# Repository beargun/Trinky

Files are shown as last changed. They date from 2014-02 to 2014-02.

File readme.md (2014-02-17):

Trinky
=========

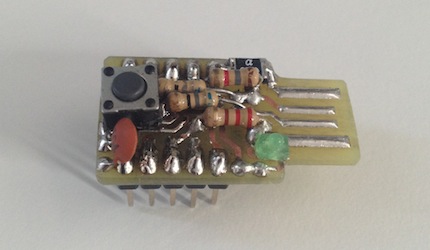
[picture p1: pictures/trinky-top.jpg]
Trinky


## A Trinket clone using only through-hole components

The goal of this project was to create a [Trinket](https://github.com/adafruit/Adafruit-Trinket-USB) clone using only through-hole components. 

### Goals

*   **Use only though-hole components**. Since there are no through-hole mini-USB B sockets, I opted for a USB A etched right on the board (similar to the [Digispark](http://digistump.com/products/1))
*   **Small footprint**. Get it at least as small as the original Trinket.
*   **Optional fuse**. I'm really fond of my USB ports, so for extra peace of mind I added a poly-fuse. I choose a surface-mount ptc fuse, as they tend to be faster than through hole versions. This fuse is optional (as it would break the first goal).  
*   **Different bootloader**. I slightly [altered the bootloader](https://github.com/beargun/Adafruit-Trinket-Gemma-Bootloader), to have it go into programming mode, only when the reset button is pressed. So when you power it up, your code will run immediately, instead of after 10 seconds.
*   **No voltage regulator**. The ATtiny85 will work on 2.7-5.5V. If you power your project using batteries, a voltage regulator will just decrease battery file. Just choose a battery with less than 5.5V. Also, I didn't have room for it. 

### Creating the board

Transfering the layout to the board using toner-transfer. You can see some paper residue on the toner. This doesn't hinder the etching
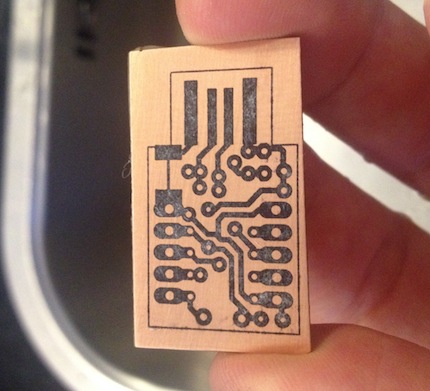
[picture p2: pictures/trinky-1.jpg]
Trinky
<br />

Etching the board in hydrochloric acid and hydrogen peroxide. I'm agitating the board using a modified cd-rom drive.
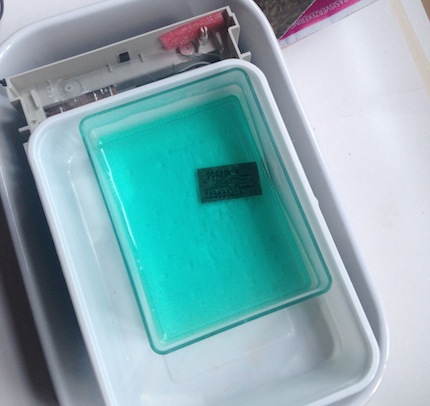
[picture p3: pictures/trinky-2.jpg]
Trinky
<br />

Almost done.
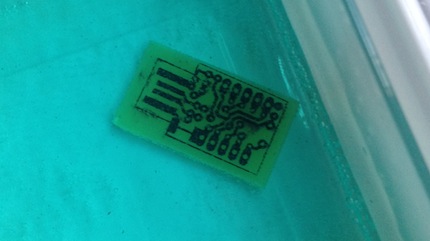
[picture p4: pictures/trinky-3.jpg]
Trinky
<br />

If you look closely you still see some copper. In hindsight I should have left it in the etching solution a bit longer.
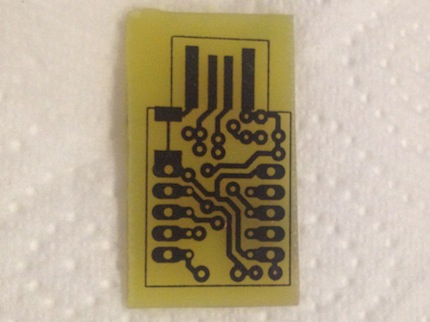
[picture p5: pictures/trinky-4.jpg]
Trinky
<br />

With the toner removed you can clearly see the copper bridge. Easily fixed with a sharp knife.
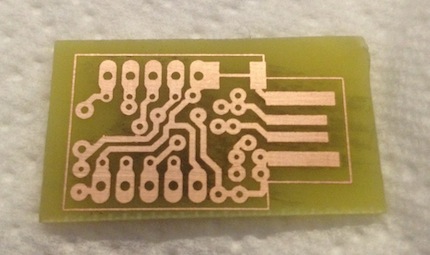
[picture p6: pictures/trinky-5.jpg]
Trinky
<br />

All fixed. Note that I also cut away some of the outline. Otherwise I couldn't test for short using my multimeter
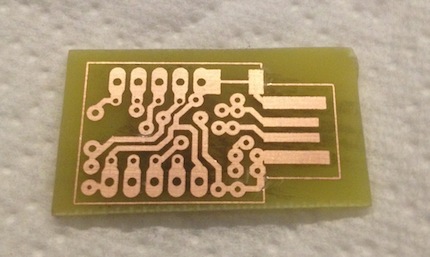
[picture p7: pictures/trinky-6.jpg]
Trinky
<br />

Holding it against the light reveals there are no more obvious shorts.
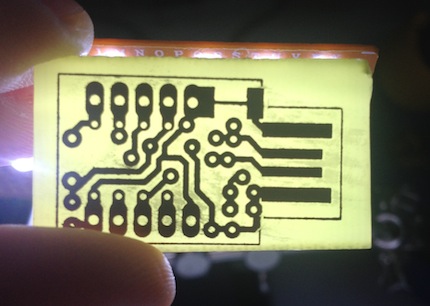
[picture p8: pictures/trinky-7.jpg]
Trinky
<br />

Holes drilled.
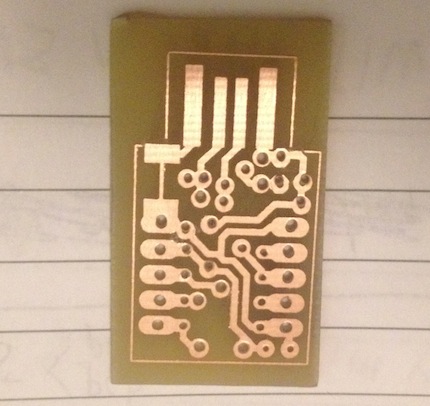
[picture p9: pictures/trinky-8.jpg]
Trinky
<br />

Outline cut using an electric scroll saw.
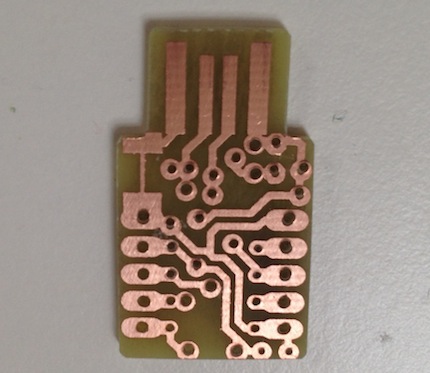
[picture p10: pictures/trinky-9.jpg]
Trinky
<br />

### Assembling the board

Since the led has to be at the top (the same side as the copper), I put the leads down, and then back up in the holes next to it. Otherwise you can't have the led flush with the board, as you have to be able to put the soldering iron underneath it.
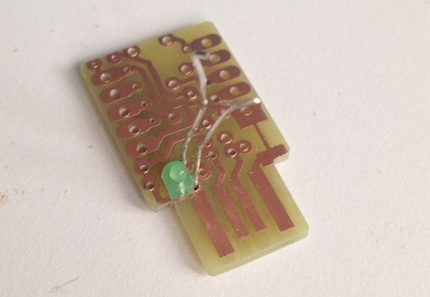
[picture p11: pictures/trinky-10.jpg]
Trinky
<br />
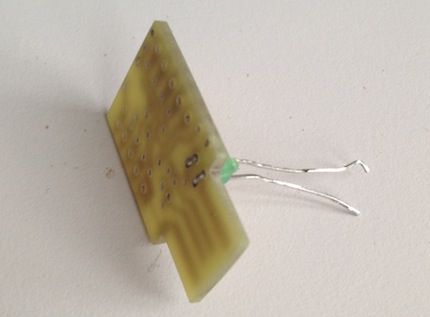
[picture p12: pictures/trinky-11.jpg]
Trinky
<br />

Next add a jumper and the two zener diodes to the underside, and solder it.
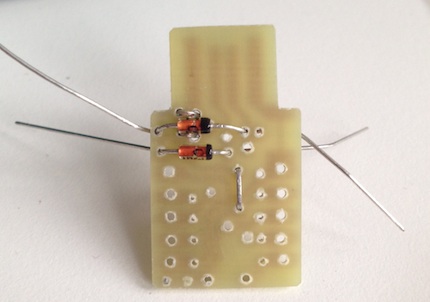
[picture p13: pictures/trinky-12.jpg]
Trinky
<br />
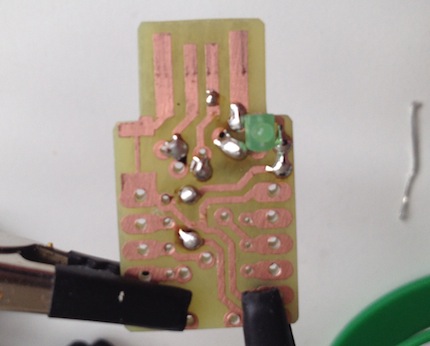
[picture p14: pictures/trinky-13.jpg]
Trinky
<br />

The resistor for the led.
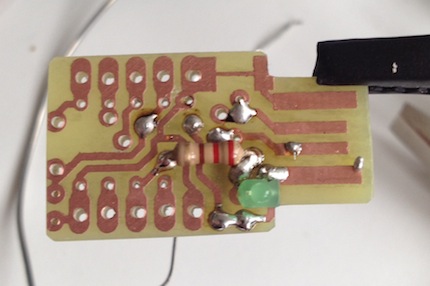
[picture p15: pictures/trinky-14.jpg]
Trinky
<br />

The two 68-Ohm resistors. **You should move the resistors more to the right, to make the button fit better.**
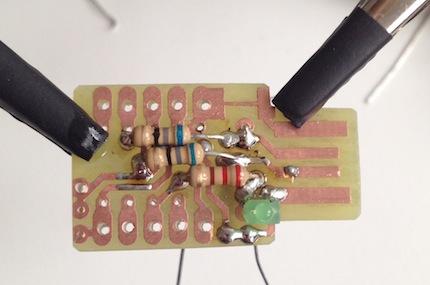
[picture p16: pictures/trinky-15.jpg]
Trinky
<br />

Note the solder bridge I accidentally made. I only noticed it when I was done, and did some final testing using my multimeter.
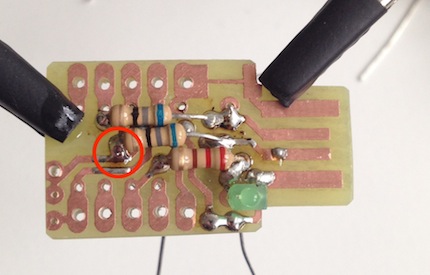
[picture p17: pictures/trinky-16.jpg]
Trinky
<br />

Remove two of the leads from the button. I also had to remove a bit of one corner. You shouldn't have to do that if you moved the resistor a bit more to the right.
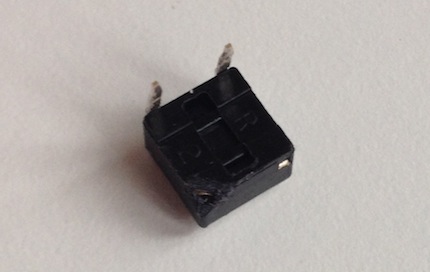
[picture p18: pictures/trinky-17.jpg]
Trinky
<br />

Here I added the button and the 1800-Ohm resistor (Trinket uses 1500-Ohm). **You should put this resistor one the bottom. As it won't really fit, once you move the two resistors, as instructed above**
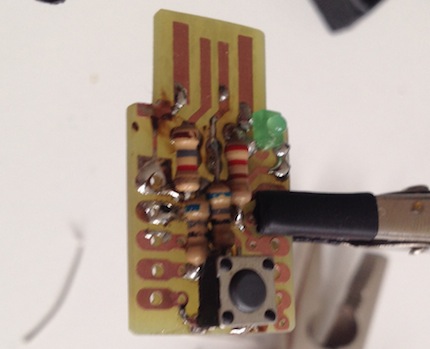
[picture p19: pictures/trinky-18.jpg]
Trinky
<br />

Here come the brains. I've already flashed my [altered bootloader](https://github.com/beargun/Adafruit-Trinket-Gemma-Bootloader) onto it.
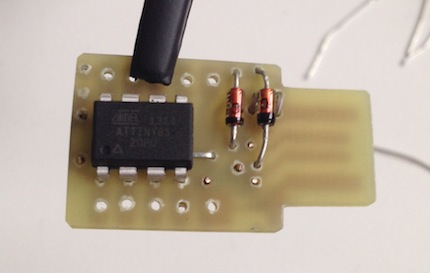
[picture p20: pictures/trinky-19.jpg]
Trinky
<br />

Bend over the pins. 
<br />I also scraped away the trace between the two pads of the poly-fuse. If you don't add the poly-fuse you should just leave it there. 
<br />Here I've also tinned the USB connector. This will make it fit better into the USB socket, and prevent the copper from oxidizing and wearing out.
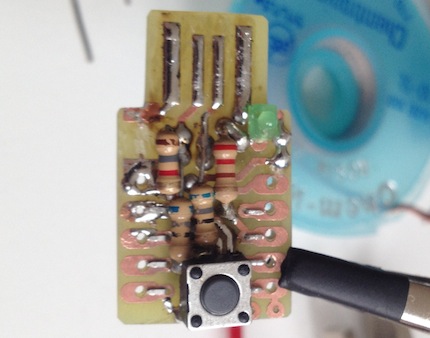
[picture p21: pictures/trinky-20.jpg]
Trinky
<br />

Here I soldered the pins, and added the optional poly-fuse. 
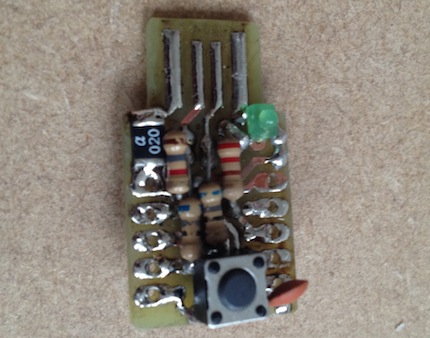
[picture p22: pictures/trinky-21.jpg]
Trinky
<br />

Because the ATtiny is at the bottom, I had to put shims under the header pins to raise them high enough to reach the board.
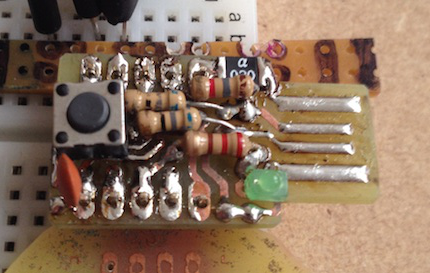
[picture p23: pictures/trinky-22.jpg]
Trinky
<br />

For a bit of extra bling, I added a few layers of nail varnish. This will prevent accidental short, oxidation and tin-whiskers (just kidding on the last one). I added some extra layers at the top right, where the board might touch the outside/shielding of the USB socket.
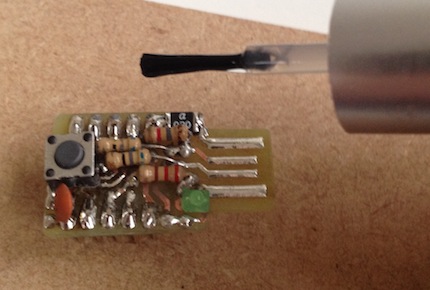
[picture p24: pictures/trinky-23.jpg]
Trinky
<br />

Too scale. The board ended up fractionally shorter (29.5mm) than the board of the real Trinket (note that mini-USB sticks out even more). It is however slightly wider. I could just cut away some more of the board, but I'd have to slightly move some components in the layout to match the width of the Trinket. Win some, lose some
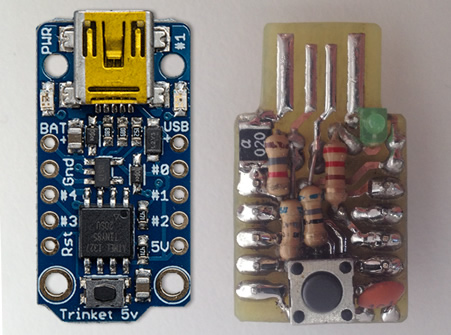
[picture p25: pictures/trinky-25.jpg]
Trinky
<br />

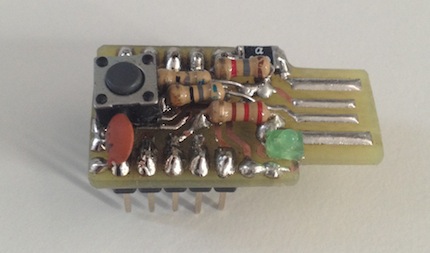
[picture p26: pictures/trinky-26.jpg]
Trinky
<br />

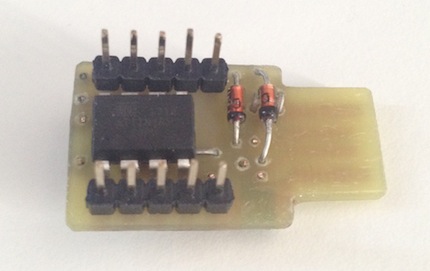
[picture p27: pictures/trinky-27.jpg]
Trinky
<br />

And yes, it works!
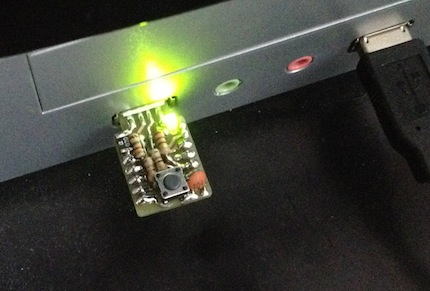
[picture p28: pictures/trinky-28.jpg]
Trinky
<br />

Thank you for watching!

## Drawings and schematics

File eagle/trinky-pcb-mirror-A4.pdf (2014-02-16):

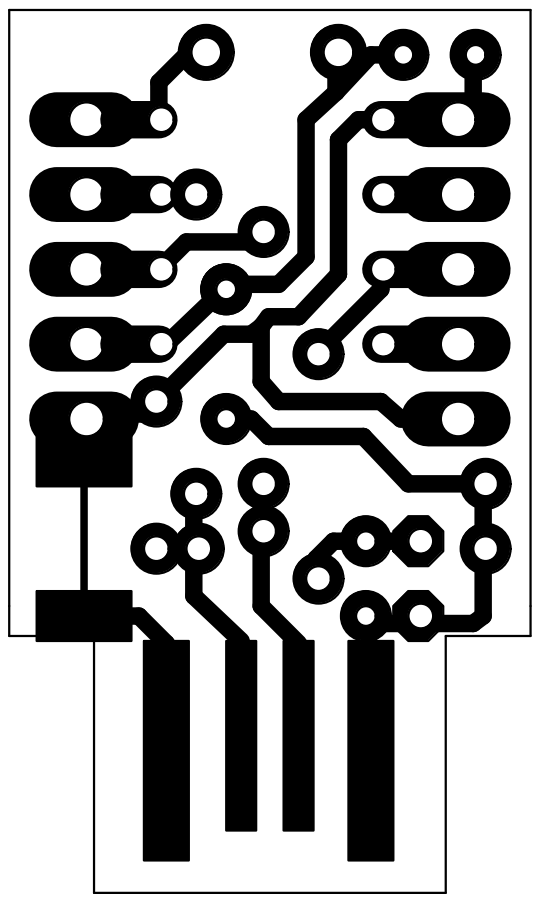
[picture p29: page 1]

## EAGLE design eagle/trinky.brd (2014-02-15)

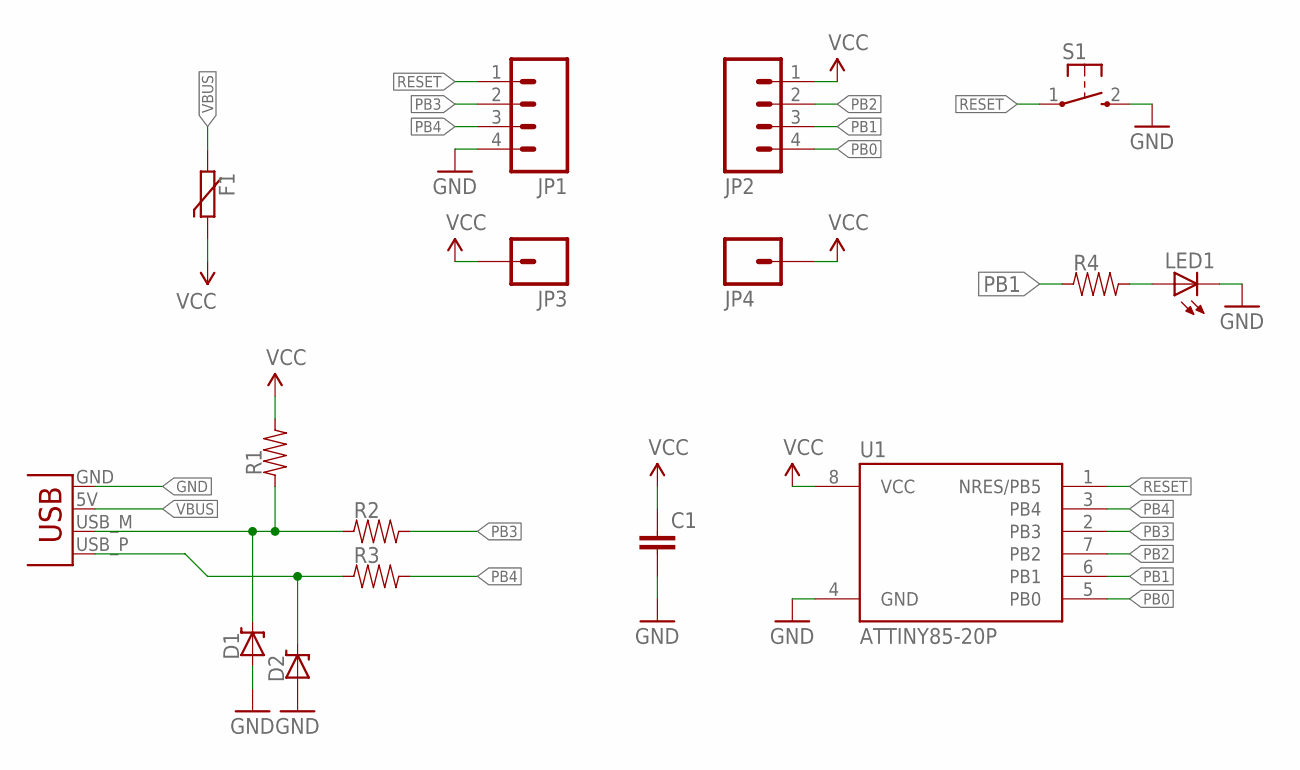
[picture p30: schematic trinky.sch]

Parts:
C1: CAPEZ; CAP-PTH-SMALLEZ
D1: ZENER-DIODE-AXIAL-0.385; SMALL-DIODE-0.385
D2: ZENER-DIODE-AXIAL-0.3; SMALL-DIODE-0.3
F1: 1812-RESETABLE-POLYFUSE; 1812-PTC-POLYFUSE
JP1, JP2: M04LONGPADS; 1X04_LONGPADS
JP3, JP4: M01PTH_LONGPAD; 1X01_LONGPAD
JP5: USBPCB; USB-A-PCB
LED1: LED3MM
R1: RESISTOR-AXIAL-0.2; AXIAL-0.2
R2, R3: RESISTOR-AXIAL-0.4; AXIAL-0.4
R4: RESISTOR-AXIAL-0.3; AXIAL-0.3
S1: TACTILE-SWITCH-2PINS-REMOVED; BUTTON-2PINS-REMOVED
U1: ATTINY85-20P; PDIP08_300MIL

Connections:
D+: D2.P$2, JP5.USB_P (D+), R3.P$1
D-: D1.P$2, JP5.USB_M (D-), R1.P$1, R2.P$1
GND: C1.2, D1.P$1, D2.P$1, JP1.4, JP5.GND, LED1.K (C), S1.2, U1.4 (GND)
unnamed: LED1.A, R4.P$2
PB0: JP2.4, U1.5 (PB0)
PB1: JP2.3, R4.P$1, U1.6 (PB1)
PB2: JP2.2, U1.7 (PB2)
PB3: JP1.2, R2.P$2, U1.2 (PB3)
PB4: JP1.3, R3.P$2, U1.3 (PB4)
RESET: JP1.1, S1.1, U1.1 (NRES/PB5)
VBUS: F1.P$1, JP5.5V (VBUS)
VCC: C1.1, F1.P$2, JP2.1, JP3.1, JP4.1, R1.P$2, U1.8 (VCC)

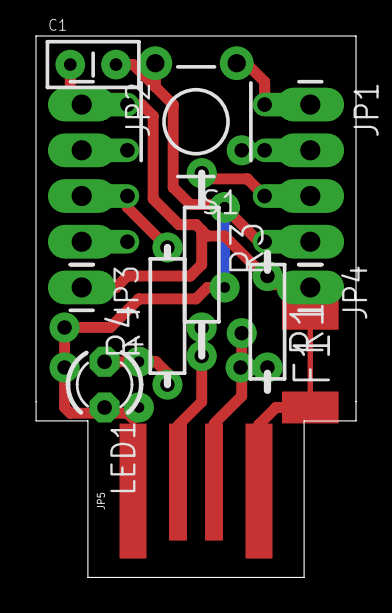
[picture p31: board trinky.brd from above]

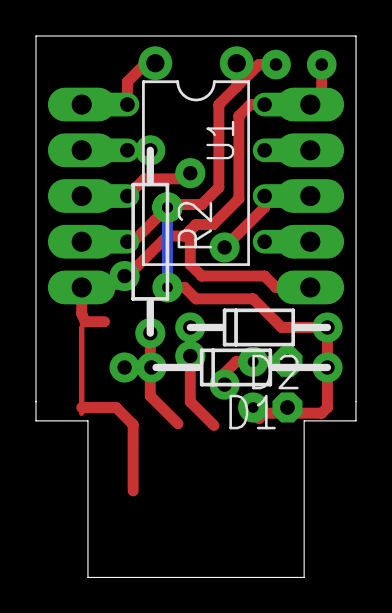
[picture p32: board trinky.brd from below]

Board: 2 copper layers, 17.8 x 30.1 mm, 16 parts (4 on the bottom side), 12 nets.

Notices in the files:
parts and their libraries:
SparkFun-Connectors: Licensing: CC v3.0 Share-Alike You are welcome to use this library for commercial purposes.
